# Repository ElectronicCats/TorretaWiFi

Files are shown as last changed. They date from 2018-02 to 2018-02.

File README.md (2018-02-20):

# Torreta ESP

El gato vigilante de la torre es un dispositivo open hardware basado en el chip ESP8266 que monitorea el estado de las torretas industriales **Patlite®**, sin modificar el circuito usted puede monitorear el tiempo de encendido y apagado de cada luz que este en la torreta, puede obtener por medio de una red WiFi o exportar sus datos en una microSD para generar despues sus reportes, facil de implementar solo debe ser agregado en uno de los espacios disponibles de la torreta.

#Features
- Tiempo acumulado de paro
- Tiempo de inicio de paro
- Access point con WebServer
- Pagina web local datos de paro y arranque
- Slot de Micro SD para almacenamiento en un archivo
- Bateria recargable 3.7v

## TODO

- Mejora de pagina de home
- Conexión Mesh entre dispositivos
- Connexión Punto a Punto entre dispositivos (P2P)
- Conexión entre dispositivos esclavos y dispositivo maestro

## LICENSING
Electronic Cats invests time and resources providing this open source design, please support Electronic Cats and open-source hardware by purchasing products from Electronic Cats!

Designed by Electronic Cats.

Firmware released under an GNU AGPL v3.0 license. See the LICENSE file for more information.

Hardware released under an CERN Open Hardware Licence v1.2. See the LICENSE_HARDWARE file for more information.

Electronic Cats is a registered trademark, please do not use if you sell these PCBs.

27 December 2017

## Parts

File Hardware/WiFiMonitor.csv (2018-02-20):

Reference | Value | Footprint | Datasheet | Field4 | Field5 | Field6 | Field8 | Fieldname | manf | Field7
U2 | 4N25 | Housings_DIP:DIP-6_W7.62mm
R6 | 10KR | Resistors_SMD:R_0603
U5 | ESP8266-12E/ESP-12E | Connectors_JAE:JAE_LY20-08P-2T_2x04x2.00mm_Straight |  | Unavailable | None | None | ESP8266-12E/ESP-12E
R2 | 2KR | Resistors_SMD:R_0603 |  |  |  |  |  | Value | RN731JTTD2101D25
R7 | 10KR | Resistors_SMD:R_0603
U3 | 4N25 | Housings_DIP:DIP-6_W7.62mm
U1 | 4N25 | Housings_DIP:DIP-6_W7.62mm
U4 | 4N25 | Housings_DIP:DIP-6_W7.62mm
R1 | 2KR | Resistors_SMD:R_0603
R5 | 10KR | Resistors_SMD:R_0603
R3 | 2KR | Resistors_SMD:R_0603
R8 | 10KR | Resistors_SMD:R_0603
U7 | DS3231MZ+ | DS3231MZ_:SOIC8_150MIL | Maxim Integrated | Real Time Clock Serial-I2C +/-5ppm SOIC8 | SOIC-8 Maxim Integrated | DS3231MZ+ | Good |  |  | 5.13 USD
R11 | 4.7KR | Resistors_SMD:R_0603
R13 | 4.7KR | Resistors_SMD:R_0603
BT2 | 3.3V | Connectors:PINHEAD1-2
BT1 | 3.3V | Battery_Holders:Keystone_1058_1x2032-CoinCell
J1 | USB_B | Connectors_USB:USB_Micro-B_Wuerth-629105150521
U6 | LM1117-3.3 | TO_SOT_Packages_SMD:SOT-223-3_TabPin2
C2 | 10uCP | Resistors_SMD:R_0603
C1 | 10uCP | Resistors_SMD:R_0603
D1 | LED_Small | LEDs:LED_0603
R9 | 100R | Resistors_SMD:R_0603
R4 | 2KR | Resistors_SMD:R_0603
IN1 | Conn_01x01_Male | PADS:PAD_5x3mm
IN2 | Conn_01x01_Male | PADS:PAD_5x3mm
IN3 | Conn_01x01_Male | PADS:PAD_5x3mm
IN4 | Conn_01x01_Male | PADS:PAD_5x3mm
COMUN1 | Conn_01x01_Male | PADS:PAD_5x3mm
COMUN2 | Conn_01x01_Male | PADS:PAD_5x3mm

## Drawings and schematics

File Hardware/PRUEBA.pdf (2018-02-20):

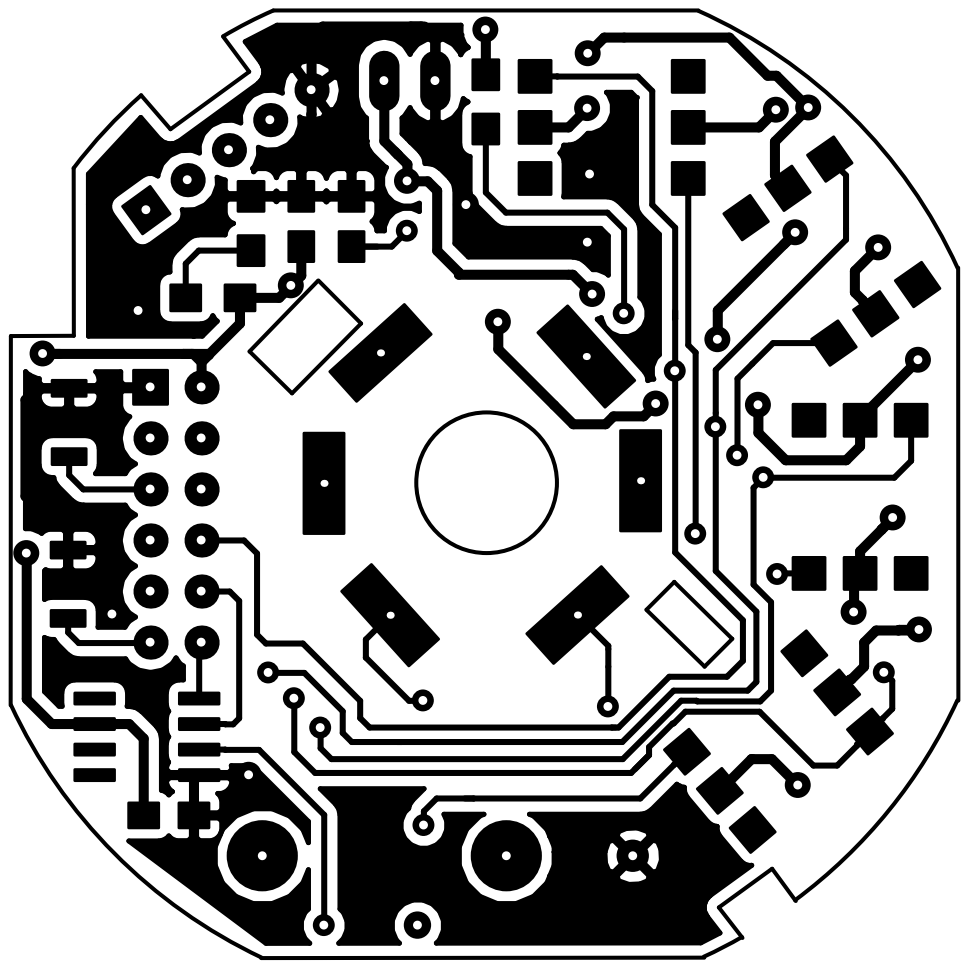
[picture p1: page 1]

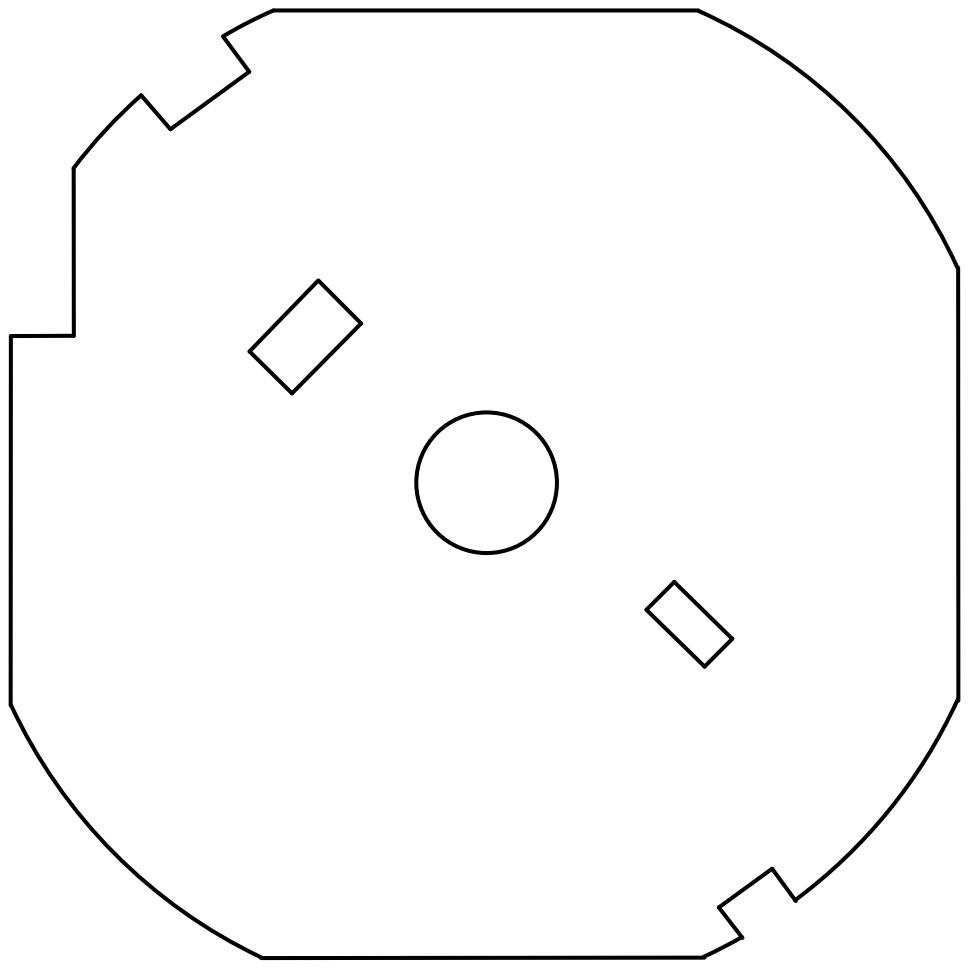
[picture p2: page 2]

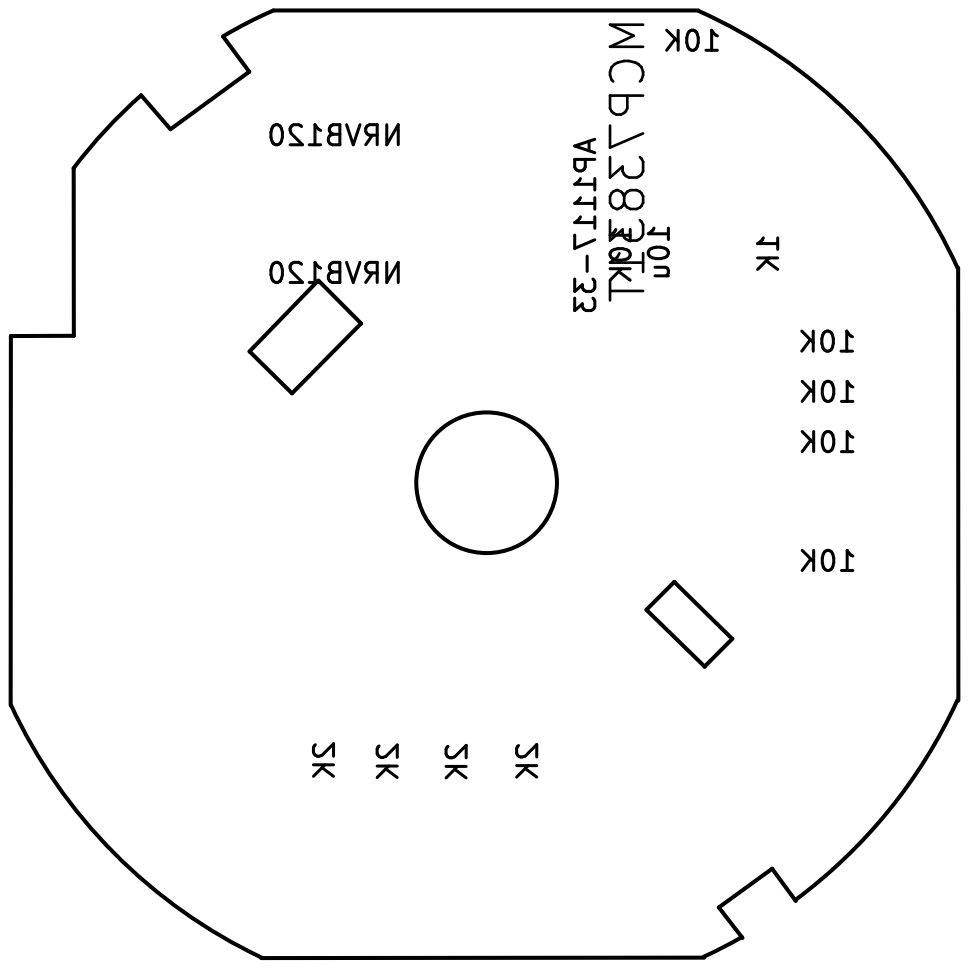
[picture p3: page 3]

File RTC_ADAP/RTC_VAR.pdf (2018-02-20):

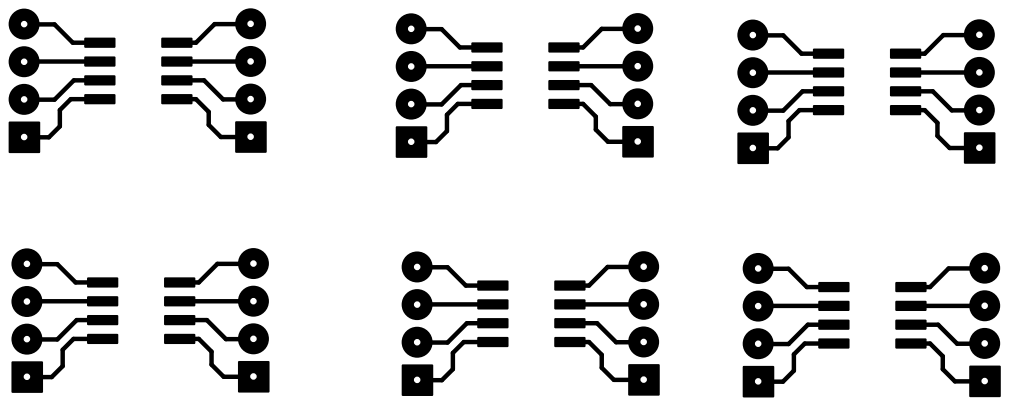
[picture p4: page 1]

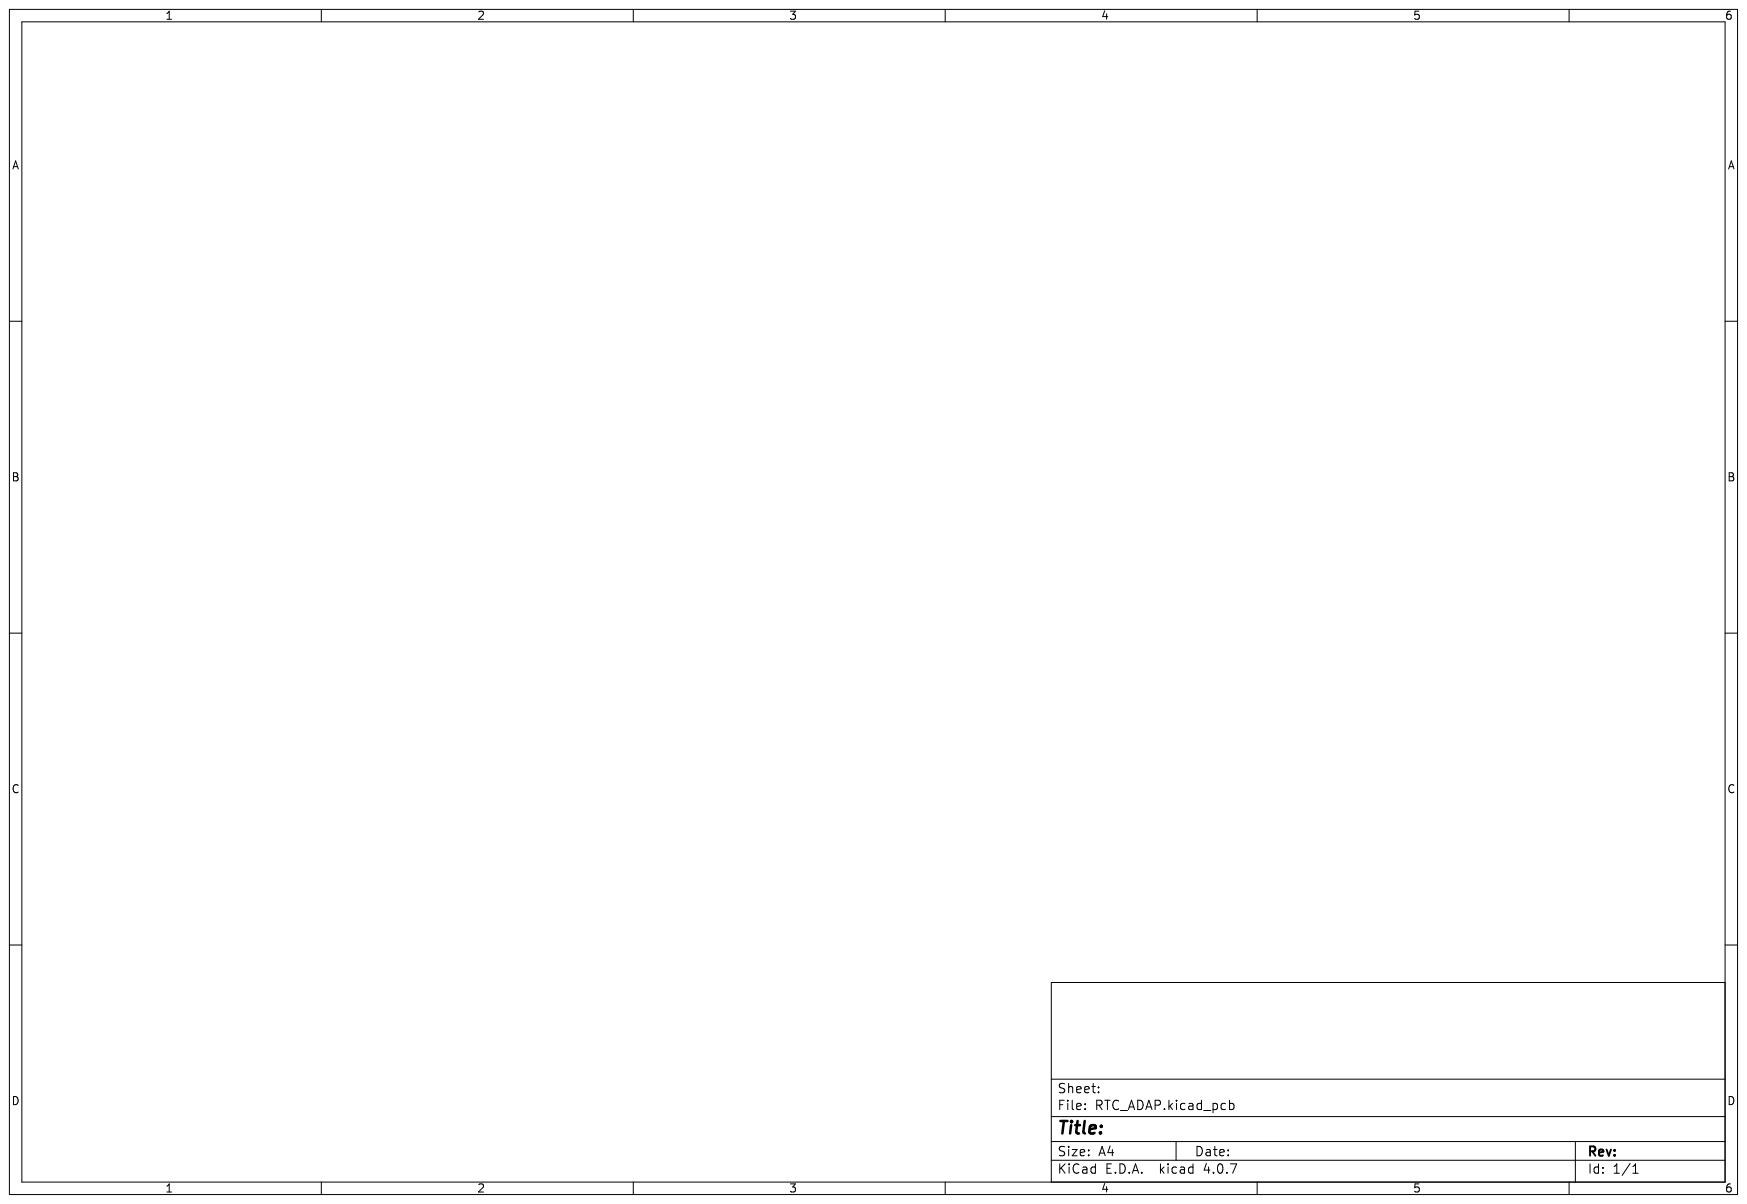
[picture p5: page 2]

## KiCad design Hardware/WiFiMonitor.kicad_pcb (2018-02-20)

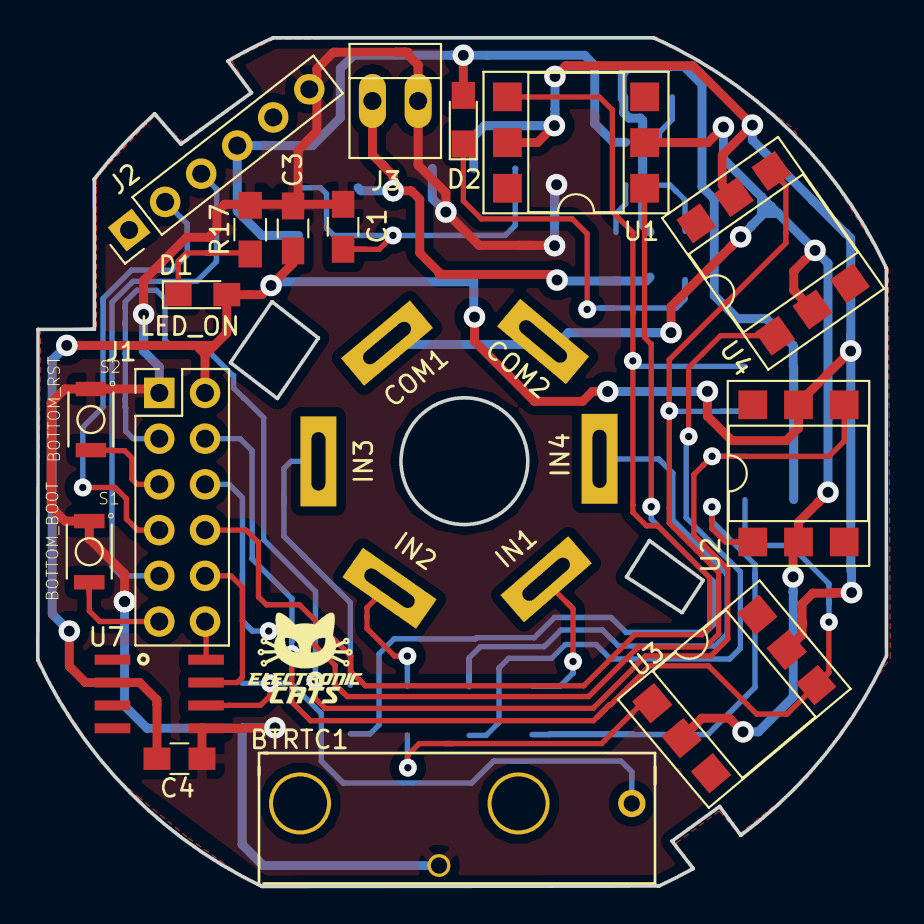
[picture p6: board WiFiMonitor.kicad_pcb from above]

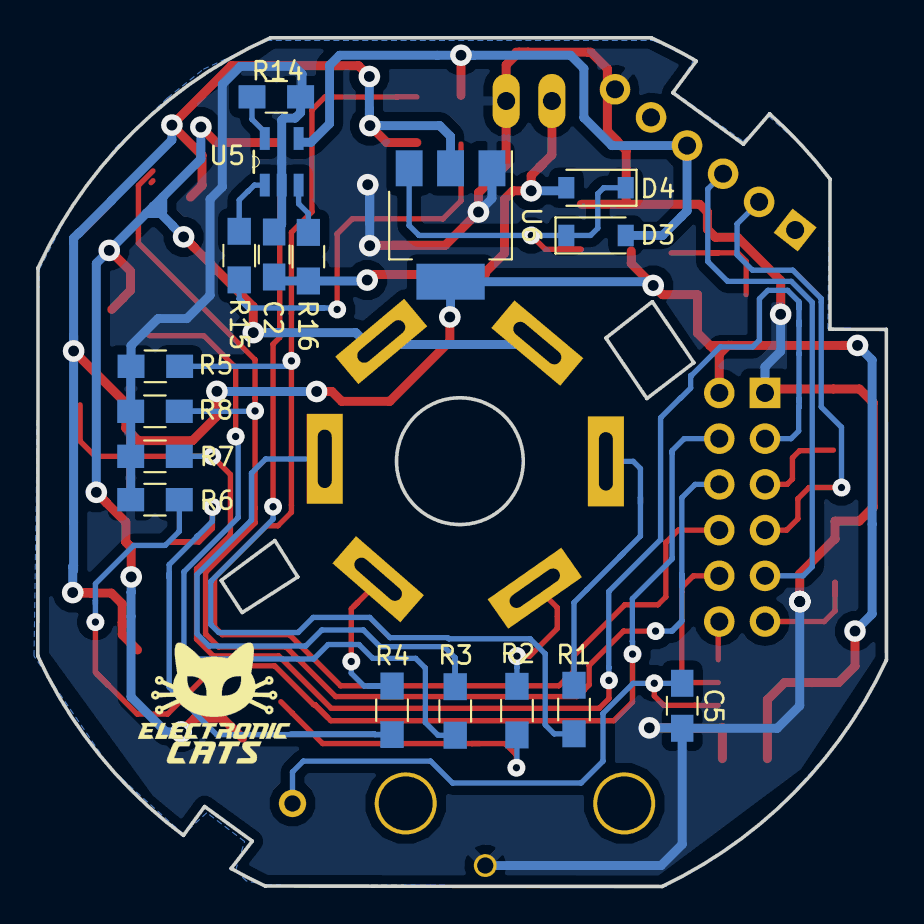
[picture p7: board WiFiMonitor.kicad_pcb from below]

Board: 2 copper layers, 47.2 x 47.1 mm, 40 parts (17 on the bottom side), 30 nets.

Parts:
BTRTC1: 3.3Va; Keystone_battery_second
C1: 2.2u; C_0805_HandSoldering
C2: 10u; C_0805_HandSoldering
C3: 4.7u; C_0805_HandSoldering
C4: 1uf; C_0805_HandSoldering
C5: .1uf; C_0805_HandSoldering
COM1: NC; PAD_4X2mmTH
COM2: TORRETA; PAD_4X2mmTH
D1: LED_ON; LED_0805_HandSoldering
D2: LED_CHAR; LED_0805_HandSoldering
D3, D4: NRVB120; D_SOD-123
IN1: 0_IN; PAD_4X2mmTH
IN2: 1_IN; PAD_4X2mmTH
IN3: 2_IN; PAD_4X2mmTH
IN4: 3_IN; PAD_4X2mmTH
J1: ADAP_ESP; Pin_Header_Straight_2x06_Pitch2.54mm
J2: FTDI; Pin_Header_Straight_1x06_Pitch2.54mm
J3: BATT; PINHEAD1-2
R1, R2, R3, R4: 2K; R_0805_HandSoldering
R5, R6, R7, R8, R14, R16: 10K; R_0805_HandSoldering
R15, R17: 1K; R_0805_HandSoldering
S1: BOTTOM_BOOT; SW_B3U-1000P
S2: BOTTOM_RST; SW_B3U-1000P
U1, U2, U3, U4: 4N25; DIP-6_W7.62mm_SMDSocket_SmallPads
U5: MCP73831T-4ADI/OT; SOT95P280X145-5N
U6: AP1117-33; SOT-223-3_TabPin2
U7: DS3231MZ+; SOIC8_150MIL

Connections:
+3V3: C3.1, C4.1, D1.2, J1.2, U1.5, U2.5, U3.5, U4.5, U6.2, U7.2
/BAT: C2.1, D3.2, J3.1, R16.1
/D0: J1.3, R6.1, U2.4
/D1: J1.4, R7.2, U3.4
/D2: J1.8, R5.1, U1.4
/D3: J1.6, R8.1, U4.4
/GPIO0: J1.11, S1.2
/RST: J1.5, S2.2
/RX: J1.7, J2.2
/SCL: J1.12, U7.8
/SDA: J1.10, U7.7
/TX: J1.9, J2.3
/VCLK: BTRTC1.1, C5.1, U7.6
GND: BTRTC1.2, C1.2, C2.2, C3.2, C4.2, C5.2, J1.1, J2.6, J3.2, R5.2, R6.2, R7.1, R8.2, R14.1, R17.2, S1.1, S2.1, U5.2, U6.1, U7.5
GNDA: COM1.1, COM2.1, U1.2, U2.2, U3.2, U4.2
unnamed: C1.1, D3.1, D4.1, U6.3
unnamed: D1.1, R17.1
unnamed: D2.1, R15.2
unnamed: IN1.1, R4.2
unnamed: IN2.1, R2.2
unnamed: IN3.1, R1.2
unnamed: IN4.1, R3.2
unnamed: R1.1, U1.1
unnamed: R2.1, U3.1
unnamed: R3.1, U4.1
unnamed: R4.1, U2.1
unnamed: R14.2, U5.5
unnamed: R15.1, U5.1
unnamed: R16.2, U5.3
VCC: D2.2, D4.2, J2.4, U5.4

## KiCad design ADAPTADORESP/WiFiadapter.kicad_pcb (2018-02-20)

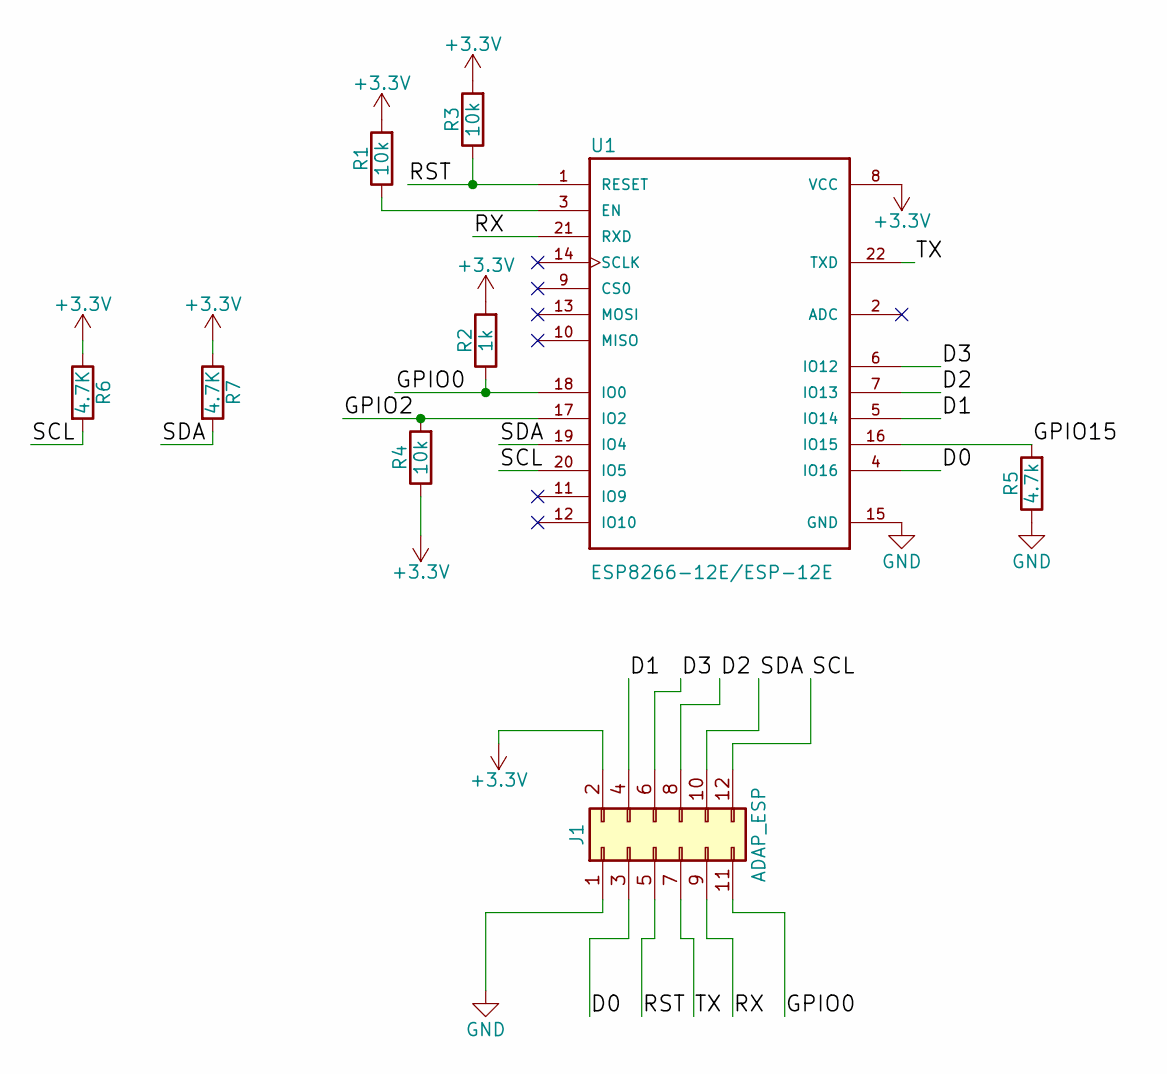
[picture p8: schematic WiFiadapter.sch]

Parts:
J1: ADAP_ESP; Pin_Header_Straight_2x06_Pitch2.54mm
R1, R3, R4: 10k; R_0805_HandSoldering
R2: 1k; R_0805_HandSoldering
R5: 4.7k; R_0805_HandSoldering
R6, R7: 4.7K; R_0805_HandSoldering
U1: ESP8266-12E/ESP-12E; XCVR_ESP8266-12E%2fESP-12E

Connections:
+3V3: J1.2, R1.2, R2.2, R3.2, R4.1, R6.1, R7.1, U1.8 (VCC)
/D0: J1.3, U1.4 (IO16)
/D1: J1.4, U1.5 (IO14)
/D2: J1.8, U1.7 (IO13)
/D3: J1.6, U1.6 (IO12)
/GPIO0: J1.11, R2.1, U1.18 (IO0)
/GPIO2: R4.2, U1.17 (IO2)
/GPIO15: R5.2, U1.16 (IO15)
/RST: J1.5, R3.1, U1.1 (RESET)
/RX: J1.9, U1.21 (RXD)
/SCL: J1.12, R6.2, U1.20 (IO5)
/SDA: J1.10, R7.2, U1.19 (IO4)
/TX: J1.7, U1.22 (TXD)
GND: J1.1, R5.1, U1.15 (GND)
unnamed: R1.1, U1.3 (EN)

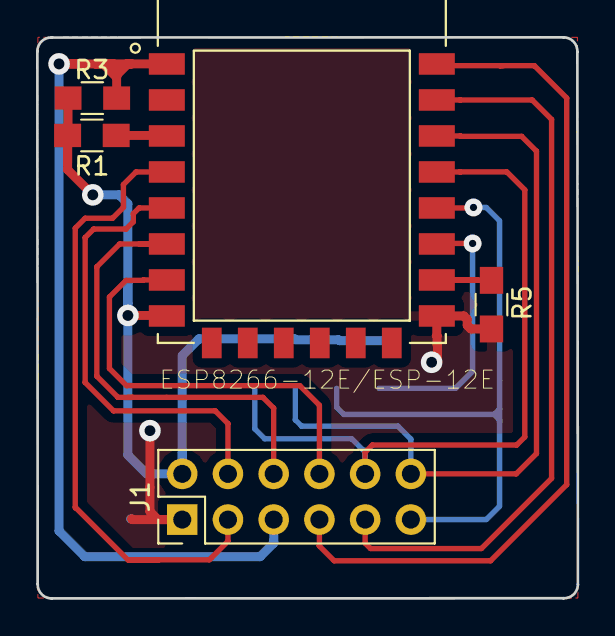
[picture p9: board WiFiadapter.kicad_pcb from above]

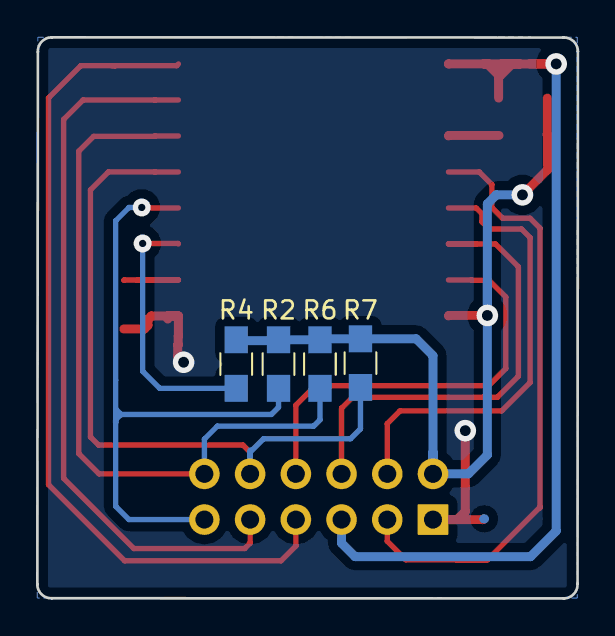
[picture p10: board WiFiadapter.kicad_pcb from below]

Board: 2 copper layers, 30.0 x 31.2 mm, 9 parts (4 on the bottom side), 15 nets.

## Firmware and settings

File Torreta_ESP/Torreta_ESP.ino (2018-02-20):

/*
 * Electromnic Cats
 * Dec 2017
 */
#include <ESP8266WiFi.h>
#include <ESP8266WebServer.h>
#include <Wire.h>
#include <ESP8266mDNS.h>
#include "RTClib.h"
#include "FS.h"


/////////////RTC//////////////

RTC_DS3231 rtc;

/////////////WEB SERVER //////////////
ESP8266WebServer server(80);

const char WiFiAPPSK[] = "12345678";

///VARIABLES DE ESTADOS///

int Amarillo = 16;//16
int AntesAmllo;
int ActualAmllo;
int contadorA1 = 0;

int Verde = 14;//14
int AntesVerde;
int ActualVerde;
int contadorV1 = 0;

///VARIABLES DE TIEMPO RTC///
DateTime TimeGlobal;
int GlobalTimeAcumSeg;
int GlobalTimeAcumMin;
int GlobalTimeAcumHor;
DateTime TimeAntesAmllo;
DateTime TimeActualAmllo;
int TimeONamarilloseg;
int TimeONamarillomin;
int TimeONamarillohor;
int TimeOFFamarilloseg;
int TimeOFFamarillomin;
int TimeOFFamarillohor;
int TimeAcumAmlloOFFseg;
int TimeAcumAmlloOFFmin;
int TimeAcumAmlloOFFhor;
int TimeAcumAmlloONseg;
int TimeAcumAmlloONmin;
int TimeAcumAmlloONhor;
DateTime TimeAntesVerde;
DateTime TimeActualVerde;
int TimeONverdeseg;
int TimeONverdemin;
int TimeONverdehor;
int TimeOFFverdeseg;
int TimeOFFverdemin;
int TimeOFFverdehor;
int TimeAcumVerdeOFFseg;
int TimeAcumVerdeOFFmin;
int TimeAcumVerdeOFFhor;
int TimeAcumVerdeONseg;
int TimeAcumVerdeONmin;
int TimeAcumVerdeONhor;
int datedia;
int datemes;
int dateyear;
int HorDif;  
int MinDif;
int SegDif; 
int tam_file;
int porce;

/*FUNCIONES*/
void handleRoot();
void handleNotFound();

void setup(void){
  //Entradas y Salidas
  pinMode(Amarillo, INPUT);
  pinMode(Verde, INPUT);          
  Serial.begin(115200);

    //HTML
  server.on("/", handleRoot);
  server.on("/down", handleDownload);
  server.on("/form", formatear);
  server.on("/inline", []()
    {
      server.send(200, "text/plain", "this works as well");
    });
  server.onNotFound(handleNotFound);
  setupWiFi();
  server.begin();
  Serial.println(F("HTTP server started"));

  //SPIFFS
    Serial.print("Iniciando SPIFFS card...");
    SPIFFS.begin();
    
  //ESP8266
  if (MDNS.begin("esp8266")) 
    {
      Serial.println(F("MDNS responder started"));
    }
  
  //RCT

  rtc.begin(); //Inicializamos el RTC
  Serial.println(F("Estableciendo Hora y fecha..."));
  //rtc.adjust(DateTime(F(__DATE__), F(__TIME__)));
  Serial.println(F("DS3231 actualizada con la hora:"));
  Serial.print(F("Fecha = "));
  Serial.print(__DATE__);
  Serial.print(F("  Hora = "));
  Serial.println(__TIME__);
  
  TimeAntesVerde=TimeAntesAmllo=rtc.now();
   datedia=TimeAntesAmllo.day();
   datemes=TimeAntesAmllo.month();
   dateyear=TimeAntesAmllo.year();
  Serial.print(F("Hora de encendido: "));
  Serial.print(TimeAntesAmllo.hour(), DEC);
  Serial.print(':');
  Serial.print(TimeAntesAmllo.minute(), DEC);
  Serial.print(':');
  Serial.print(TimeAntesAmllo.second(), DEC);
  Serial.println("");
  Serial.print(TimeAntesAmllo.day(), DEC);
  Serial.print('/');
  Serial.print(TimeAntesAmllo.month(), DEC);
  Serial.print('/');
  Serial.print(TimeAntesAmllo.year(), DEC);
  Serial.println("");
}

void loop(void){
  server.handleClient();
  //Calculo de tiempocon RTC
  ActualAmllo= digitalRead(Amarillo); 
  ActualVerde = digitalRead(Verde);
  
  if (AntesAmllo != ActualAmllo) //ha habido un cambio de estado
  {
    if (ActualAmllo==1)
    {
  TimeActualAmllo = rtc.now();
  TimeONamarillohor = TimeActualAmllo.hour();  //Para poder restarle  
  TimeONamarillomin = TimeActualAmllo.minute();  //Para poder restarle
  TimeONamarilloseg = TimeActualAmllo.second();  //Tiempo de Cambios
  TimeOFFamarillohor = 0;  //Para poder restarle  
  TimeOFFamarillomin = 0;  //Para poder restarle
  TimeOFFamarilloseg = 0;  //Tiempo de Cambios

      Serial.println(F("AMARILLO ON "));
      DiferenciaTiempos(TimeActualAmllo, TimeAntesAmllo, TimeAcumAmlloOFFhor, TimeAcumAmlloOFFmin, TimeAcumAmlloOFFseg);
      TimeAcumAmlloOFFseg=GlobalTimeAcumSeg;
      TimeAcumAmlloOFFmin=GlobalTimeAcumMin;
      TimeAcumAmlloOFFhor=GlobalTimeAcumHor;
      Serial.print(F("Time Actual: "));
      ImpresionDeTiempos (TimeActualAmllo);
      Serial.println("");
      Serial.print(F("Time Antes: "));
      ImpresionDeTiempos (TimeAntesAmllo);
      Serial.println("");;
      contadorA1++;
    }

    else //actualA==0
      {
        TimeActualAmllo = rtc.now();
        TimeOFFamarillohor = TimeActualAmllo.hour();  //Para poder restarle  
        TimeOFFamarillomin = TimeActualAmllo.minute();  //Para poder restarle
        TimeOFFamarilloseg = TimeActualAmllo.second();  //Tiempo de Cambios
        Serial.print(F("AMARILLO OFF "));
        DiferenciaTiempos(TimeActualAmllo, TimeAntesAmllo, TimeAcumAmlloONhor, TimeAcumAmlloONmin, TimeAcumAmlloONseg);
        TimeAcumAmlloONseg=GlobalTimeAcumSeg;
        TimeAcumAmlloONmin=GlobalTimeAcumMin;
        TimeAcumAmlloONhor=GlobalTimeAcumHor;
        Serial.print(F("Time Actual: "));
        ImpresionDeTiempos (TimeActualAmllo);
        Serial.println(F(""));
        Serial.print(F("Time Antes: "));
        ImpresionDeTiempos (TimeAntesAmllo);
        Serial.println("");
        sdcard(contadorA1, TimeONamarillohor, TimeONamarillomin, TimeONamarilloseg, TimeOFFamarillohor, TimeOFFamarillomin, TimeOFFamarilloseg, TimeAcumAmlloONhor, TimeAcumAmlloONmin, TimeAcumAmlloONseg);
      }
      TimeAntesAmllo = TimeActualAmllo;
      AntesAmllo = ActualAmllo;
      porce=(tam_file/3600);
      Serial.println(tam_file);
      Serial.println(porce);
  }
     if (AntesVerde != ActualVerde) //ha habido un cambio de estado
  {
    if (ActualVerde==1)
    {
      TimeActualVerde = rtc.now();
     TimeONverdehor = TimeActualVerde.hour();  //Para poder restarle  
     TimeONverdemin = TimeActualVerde.minute();  //Para poder restarle
     TimeONverdeseg = TimeActualVerde.second();  //Tiempo de Cambios
     TimeOFFverdehor = 0;  //Para poder restarle  
     TimeOFFverdemin = 0;  //Para poder restarle
     TimeOFFverdeseg = 0;  //Tiempo de Cambios
      Serial.print("VERDE ON");
      DiferenciaTiempos(TimeActualVerde, TimeAntesVerde, TimeAcumVerdeOFFhor, TimeAcumVerdeOFFmin, TimeAcumVerdeOFFseg);
      TimeAcumVerdeOFFseg=GlobalTimeAcumSeg;
      TimeAcumVerdeOFFmin=GlobalTimeAcumMin;
      TimeAcumVerdeOFFhor=GlobalTimeAcumHor;
      Serial.print(F("Time Actual: "));
      ImpresionDeTiempos (TimeActualVerde);
      Serial.println(F(""));
      Serial.print(F("Time Antes: "));
      ImpresionDeTiempos (TimeAntesVerde);
      Serial.println("");
      contadorV1++;
    }
    else //actualA==0
      {
        TimeActualVerde = rtc.now();
     TimeOFFverdehor = TimeActualVerde.hour();  //Para poder restarle  
     TimeOFFverdemin = TimeActualVerde.minute();  //Para poder restarle
     TimeOFFverdeseg = TimeActualVerde.second();  //Tiempo de Cambios
        Serial.print("VERDE OFF");
        DiferenciaTiempos(TimeActualVerde, TimeAntesVerde, TimeAcumVerdeONhor, TimeAcumVerdeONmin, TimeAcumVerdeONseg);
        TimeAcumVerdeONseg=GlobalTimeAcumSeg;
        TimeAcumVerdeONmin=GlobalTimeAcumMin;
        TimeAcumVerdeONhor=GlobalTimeAcumHor;
        Serial.print(F("Time Actual: "));
        ImpresionDeTiempos (TimeActualVerde);
        Serial.println(F(""));
        Serial.print(F("Time Antes: "));
        ImpresionDeTiempos (TimeAntesVerde);
        Serial.println("");
      }
      TimeAntesVerde = TimeActualVerde;
      AntesVerde = ActualVerde;
  } 
  delay (10);
}

void setupWiFi()
{
  WiFi.mode(WIFI_AP);
  // Do a little work to get a unique-ish name. Append the
  // last two bytes of the MAC (HEX'd) to "Thing-":
  uint8_t mac[WL_MAC_ADDR_LENGTH];
  WiFi.softAPmacAddress(mac);
  String macID = String(mac[WL_MAC_ADDR_LENGTH - 2], HEX) +
                 String(mac[WL_MAC_ADDR_LENGTH - 1], HEX);
  macID.toUpperCase();
  String AP_NameString = "Torreta" + macID;

  char AP_NameChar[AP_NameString.length() + 1];
  memset(AP_NameChar, 0, AP_NameString.length() + 1);

  for (int i=0; i<AP_NameString.length(); i++)
  AP_NameChar[i] = AP_NameString.charAt(i);
 
  WiFi.softAP(AP_NameChar, WiFiAPPSK);
}
//HTML
void handleRoot() {
  //Serial.println("Conectado a html");
  char temp[2500];
    snprintf (temp, 2500,
          "<html>\
            <head>\
            <meta http-equiv='refresh' content='1'/>\
            <title>\Torreta ESP</title>\
            <STYLE type='text/css'>\
            H1 { text-align: center}\
            </STYLE>\
            <style>\
            body { background-color: #000000; font-family: Arial, Helvetica, Sans-Serif; Color: #FFFFFF; }\
            </style>\
            <script type='text/javascript'>\
            function ConfirmDemo() {\
            var mensaje = confirm('Al iniciar un nuevo historial se borraran los datos anteriores Desea continual?');\
            if (mensaje) {document.historial.submit();}\
            else {alert('Seguimiento historial')}\
            }\
            </script>\
            </head>\
            <body>\
              <h1>TORRETA</h1>\
              <style>\
              div   { text-align: center; }\
              table { margin: auto; }\
              </style>\
              <table>\
              </tr>\
              <th>\Memoria utilizada:</th>\
              <td>\%02d%</td>\
              </tr>\
              </table>\
              </div>\
              <table>\
                <tr>\
                  <th>\Color de torreta</th>\
                  <th>\Estado</th>\
                  <th>\Fecha</th>\
                  <th>\Veces Encendido</th>\
                  <th>\Hora encendido</th>\
                  <th>\Hora apagado</th>\
                  <th>\Tiempo Encendido</th>\
                </tr>\
                <tr>\
                  <td>\Amarillo</td>\
                  <td>\%01d</td>\
                  <td>\%02d/%02d/%02d</td>\
                  <td>\%01d</td>\
                  <td>\%02d:%02d:%02d</td>\
                  <td>\%02d:%02d:%02d</td>\
                  <td>\%02d:%02d:%02d</td>\
                </tr>\
                <tr>\
                  <td>\Verde</td>\
                  <td>\%01d</td>\
                  <td>\%02d/%02d/%02d</td>\
                  <td>\%01d</td>\
                  <td>\%02d:%02d:%02d</td>\
                  <td>\%02d:%02d:%02d</td>\
                  <td>\%02d:%02d:%02d</td>\
                </tr>\
              </table>\
              <div>\
              <style type='text/css'>\
              <!-- .centrar { text-align:center; }-->\
              </style>\
              <a href='/down'>Descargar historial</a>\
              <form name=historial action='/form'>\
              <input type='button' onclick='ConfirmDemo()' value='Nuevo historial' />\
              </form>\
            </body>\
            </html>"
         ,porce
         ,ActualAmllo, datedia, datemes, dateyear, contadorA1, TimeONamarillohor, TimeONamarillomin, TimeONamarilloseg,TimeOFFamarillohor, TimeOFFamarillomin,TimeOFFamarilloseg, TimeAcumAmlloONhor, TimeAcumAmlloONmin, TimeAcumAmlloONseg
         ,ActualVerde, datedia, datemes, dateyear, contadorV1, TimeONverdehor, TimeONverdemin, TimeONverdeseg, TimeOFFverdehor, TimeOFFverdemin, TimeOFFverdeseg, TimeAcumVerdeONhor, TimeAcumVerdeONmin, TimeAcumVerdeONseg
        );
   server.send ( 200, "text/html", temp );
}

void handleNotFound(){
  String message = "File Not Found\n\n";
  message += "URI: ";
  message += server.uri();
  message += "\nMethod: ";
  message += (server.method() == HTTP_GET)?"GET":"POST";
  message += "\nArguments: ";
  message += server.args();
  message += "\n";
  for (uint8_t i=0; i<server.args(); i++){
    message += " " + server.argName(i) + ": " + server.arg(i) + "\n";
  }
  server.send(404, "text/plain", message);
}

void DiferenciaTiempos(DateTime TimeActual, DateTime TimeAntes, int TimeAcumHor, int TimeAcumMin, int TimeAcumSeg)
{
  GlobalTimeAcumSeg=0;
  GlobalTimeAcumMin=0;
  GlobalTimeAcumHor=0;
  int Hor = TimeActual.hour();  //Para poder restarle  
  int Min = TimeActual.minute();  //Para poder restarle
   SegDif = (TimeActual.second()-TimeAntes.second());  //Tiempo de Cambios
  if(SegDif<0)
  {
    SegDif = 60 + SegDif;
    Min = Min - 1;  //TimeActual.minute() - 1
  }
  TimeAcumSeg = SegDif + TimeAcumSeg; //Segundos totales
  MinDif = Min - TimeAntes.minute();
  if(MinDif<0)
  {
    MinDif = 60 + MinDif;
    Hor = Hor - 1;  //TimeActual.hour() - 1
  }
  TimeAcumMin = MinDif + TimeAcumMin; //Minutos totales
   HorDif = Hor - TimeAntes.hour();
  TimeAcumHor = HorDif + TimeAcumHor; //Horas totales

  int mindiv=TimeAcumSeg/60;
  if(0<mindiv)
  {
    TimeAcumMin=TimeAcumMin+mindiv;
    TimeAcumSeg=TimeAcumSeg-(mindiv*60);
  }
  GlobalTimeAcumSeg=TimeAcumSeg;
  int hordiv=TimeAcumSeg/60;
  if(0<mindiv)
  {
    TimeAcumHor=TimeAcumHor+hordiv;
    TimeAcumMin=TimeAcumMin-(hordiv*60);
  }
  GlobalTimeAcumMin=TimeAcumMin;
  GlobalTimeAcumHor=TimeAcumHor;
 
  Serial.print(F("Acumulado:"));
  Serial.print(HorDif);
  Serial.print(':');
  Serial.print(MinDif);
  Serial.print(':');
  Serial.print(SegDif);
  Serial.println(F(""));
}

void ImpresionDeTiempos(DateTime TimeGlobal) 
{
  Serial.print(TimeGlobal.hour());
  Serial.print(':');
  Serial.print(TimeGlobal.minute());
  Serial.print(':');
  Serial.print(TimeGlobal.second());
}

void sdcard(int count, int horON, int minON, int segON, int OFFhor, int OFFmin, int OFFseg, int acuhr, int acumin, int acumseg)
{
  int tam;
  String dataString="";
  dataString += String(datedia);//valor que va en el contador
  dataString +="/";
  dataString += String(datemes);//valor que va en el contador
  dataString +="/";
  dataString += String(dateyear);//valor que va en el contador
  dataString +=","; //la coma deja divir en columnas
  dataString += String(count);//valor que va en el contador
  dataString +=","; //la coma deja divir en columnas
  dataString += String(horON);//valor que va en el contador
  dataString +=":";
  dataString += String(minON);//valor que va en el contador
  dataString +=":";
  dataString += String(segON);//valor que va en el contador
  dataString +=","; //la coma deja divir en columnas
  dataString += String(OFFhor);//valor que va en el contador
  dataString +=":";
  dataString += String(OFFmin);//valor que va en el contador
  dataString +=":";
  dataString += String(OFFseg);//valor que va en el contador
  dataString +=","; //la coma deja divir en columnas
  dataString += String(HorDif);//valor que va en el contador
  dataString +=":";
  dataString += String(MinDif);//valor que va en el contador
  dataString +=":";
  dataString += String(SegDif);//valor que va en el contador
  dataString +=","; //la coma deja divir en columnas
  dataString += String(acuhr);//valor que va en el contador
  dataString +=":";
  dataString += String(acumin);//valor que va en el contador
  dataString +=":";
  dataString += String(acumseg);//valor que va en el contador
  dataString +=","; //la coma deja divir en columnas

  // open file for writing
  File f = SPIFFS.open("/f.txt", "a+");
  if (!f) {
      Serial.println("file open failed");
  }
  Serial.println("====== Writing to SPIFFS file =========");
  // write strings to file
  f.println(dataString);
  Serial.println(dataString);
      int size=f.size();
     if (size>360000)
        {
         Serial.print("formatear");
         Serial.print("the memory will finish");
         //Next lines have to be done ONLY ONCE!!!!!When SPIFFS is formatted ONCE you can comment these lines out!!
         Serial.println("Please wait 30 secs for SPIFFS to be formatted");
         SPIFFS.format();
         Serial.println("Spiffs formatted");
         Serial.print(size);
        }
  tam_file=size;
  f.close();
  }
  void handleDownload() 
  {
    int32_t time = millis();
    // open file for reading
    File dataFile = SPIFFS.open("/f.txt", "a+");//guardar mas datos
    int fsizeDisk = dataFile.size();
    Serial.print("fsizeDisk: "); Serial.println(fsizeDisk);

    String WebString = "";
    WebString += "HTTP/1.1 200 OK\r\n";
    WebString += "Content-Type: text/plain\r\n";
    WebString += "Content-Disposition: attachment; filename=\"datalog.csv\"\r\n";
    WebString += "Content-Length: " + String(fsizeDisk) + "\r\n";
    WebString += "\r\n";
    server.sendContent(WebString);

    char buf[1024];
    int siz = dataFile.size();
    while(siz > 0) {
        size_t len = std::min((int)(sizeof(buf) - 1), siz);
        dataFile.read((uint8_t *)buf, len);
        server.client().write((const char*)buf, len);
        siz -= len;
    }
    Serial.print(siz);
    Serial.println(" Bytes left!");

    dataFile.close();
    time = millis() - time;
    Serial.print(time); Serial.println(" ms elapsed");
}
void formatear()
{
         Serial.print("formatear");
         Serial.print("the memory will finish");
         //Next lines have to be done ONLY ONCE!!!!!When SPIFFS is formatted ONCE you can comment these lines out!!
         Serial.println("Please wait 30 secs for SPIFFS to be formatted");
         SPIFFS.format();
         Serial.println("Spiffs formatted");
         Serial.print(tam_file);
  }

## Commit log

2017-10-13 Depuración
    Cambio de usurio y contraseña
    Print en serial
    Cambio en lectura de variables
2017-11-13 Reloj RTC
    Inicialización de algoritmo para reloj RTC
2017-11-15 Tiempo de encendido y apagado RTC
    diferencia de tiempo de cambio
    unicamente con entrada D0 (amarillo)
2017-11-27 Libreria "ImpresionDeTiempos"
    en esta libreria se manda el parametro DateTime y regresa la impresion serial del tiempo (hora, minuto y segundo)
2017-12-25 HTML_SAVEDATA
    Agrege datos en la pagina web y descarga datos en un excel desde el server
    [HIS_TORRETA.xlsx]
2017-12-27 Optimizado Serial print en memoria
2017-12-27 Agregado esquematico
    [WiFiMonitor.kicad_pcb, WiFiMonitor.sch]
2017-12-27 TXTTIMEDEAD
    Edicion de formato en el txt e identificacion del tiempo muerto(amarillo)
2017-12-27 Agregado la descarga de archivo
2017-12-28 SPIFFSDATO
    Guarda el historial completo, borrar las horas en apagado del cerial print, agregar descarga en html
2018-01-01 Esch-torreta
    RTC DS3231 8 PINES Y USB-B CON REGULADOR LM 1117 3.3V
    [WiFiMonitor.sch]
2018-01-03 Charger
    Agregue el MCP73831 manager y el conector de la pila, tambien se cambio el ESP por el conector acondicionado para el esp.
    [WiFiMonitor.csv, WiFiMonitor.kicad_pcb, WiFiMonitor.sch]
2018-01-04 Final
    Corregi nombres, y agregue el circuito de programación
    [HIS_TORRETA.xlsx, WiFiMonitor.kicad_pcb, WiFiMonitor.sch]
2018-01-05 PULL_UP_BOTTON
    RESISTENCIAS CORREGIDAS PULL UP DEL RTC Y CAMBIO DE BOTON
    [WiFiMonitor.kicad_pcb, WiFiMonitor.sch]
2018-01-05 VCC
    Etiqueta VCC y VCC ESP cambiado por 3.3
    [WiFiMonitor.sch]
2018-01-12 ADAP_MEDIDAS
    Adaptador del ESP8266 para programación. Y modificacion del esquematico placa principal para el adaptador.
    [WiFiMonitor.kicad_pcb, WiFiMonitor.sch, WiFiadapter.kicad_pcb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]
2018-01-13 PCBS_Adap_mon
    Correxión del RX y TX del adaptador, PCB monitor doble capa.
    [WiFiMonitor.kicad_pcb, WiFiMonitor.sch, WiFiadapter.kicad_pcb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]
2018-01-13 Tracks fix
    [WiFiMonitor.kicad_pcb, WiFiMonitor.sch, WiFiadapter.kicad_pcb]
2018-01-14 PCB_PISTAS
    Reacomodo de pistas
    [RTC_ADAP.kicad_pcb, RTC_ADAP.sch, WiFiMonitor.kicad_pcb]
2018-01-17 PADS_TH
    Pads de los voltajes de entradas en Through-Hole y espacio para el tornillo en el centro,
    [WiFiMonitor.kicad_pcb, WiFiMonitor.sch]
2018-01-18 RTC_capacitor
    Se agrego el capacitor al DS3231 a pcb y esquematico. Movimiento de vista 3D a los conectores, y cambio de pistas.
    [WiFiMonitor.kicad_pcb, WiFiMonitor.sch]
2018-01-18 Fix vias at the power side, and fix labels
    [WiFiMonitor.kicad_pcb]
2018-01-19 Fix vias and stuff FTW
    [WiFiMonitor.kicad_pcb]
2018-01-19 Added logo EC
    [WiFiMonitor.kicad_pcb]
2018-01-19 Auto stash before merge of "HARDWARER" and "origin/HARDWARER"
    6 PINES FTDI
    [WiFiMonitor.kicad_pcb, WiFiMonitor.sch]
2018-01-19 Adapter_TXRX
    TX RX change
    [WiFiadapter.kicad_pcb, WiFiadapter.sch]
2018-01-19 Pista_near
    Move
    [WiFiMonitor.kicad_pcb]
2018-01-19 pads_in
    move
    [WiFiMonitor.kicad_pcb]
2018-01-19 pads2
    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
    [WiFiMonitor.kicad_pcb]
2018-01-19 pads3
    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
    [WiFiMonitor.kicad_pcb]
2018-01-19 pads4
    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
    [WiFiMonitor.kicad_pcb]
2018-01-19 pcb_adapter
    Redondeo de la placa
    [WiFiadapter.kicad_pcb]
2018-01-20 pads4_1
    edge board
    [WiFiMonitor.kicad_pcb]
2018-01-20 pads4_21
    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
    [WiFiMonitor.kicad_pcb]
2018-01-20 pads4_22
    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
    [WiFiMonitor.kicad_pcb]
2018-01-20 pads4_23
    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
    [WiFiMonitor.kicad_pcb]
2018-01-23 modificacion_pistas
    reacomodo
    [WiFiMonitor-B.Cu.gbl, WiFiMonitor-B.Mask.gbs, WiFiMonitor-B.Paste.gbp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]
2018-01-23 Gerbers
    generar nuevos
    [WiFiMonitor-B.Cu.gbl, WiFiMonitor-B.Mask.gbs, WiFiMonitor-B.Paste.gbp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]
2018-01-23 gerberzip
    comprimir
2018-01-29 size_file
    Conocer el espacio libre respecto al tamaño del archivo generado en la memoria flash.
2018-02-01 Botton confirm new historial
    Boton de confirmar crear nuevo historial en el servidor
2018-02-03 Access_point
    Sequito el modo station wifi
2018-02-12 CHANGE TX-RX CASE BATTERY RTC AND CAPACITOR RTC
    [WiFiMonitor.kicad_pcb, WiFiMonitor.sch]
